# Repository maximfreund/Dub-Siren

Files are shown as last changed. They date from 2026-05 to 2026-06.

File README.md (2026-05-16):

# Dub Siren

> Fork of [xioTechnologies/Dub-Siren](https://github.com/xioTechnologies/Dub-Siren) by [Seb Madgwick](https://github.com/xioTechnologies).
> Changes in this fork: replaced discontinued components, updated BOM, added dub glide bass preset, added simulate.py for sound preview

A monophonic synthesiser comprised of an LFO, VCO, and Delay.  The synthesiser is controlled by 9 potentiometers and 3 buttons.  Configurations can be stored to 1 of 10 preset keys.  Pressing a preset key will override the potentiometers and buttons with the stored configuration.

The processor used is [PIC32MZ](http://www.microchip.com/wwwproducts/en/PIC32MZ2048EFH064).  This is a 32-bit device with a FPU, 512 KB of RAM, 2 MB of program space, running at 252 MHz.  The processor is deliberately over-spec'd to simplify development and allow new ideas to be explored in the future.  The [DAC](https://www.cirrus.com/products/cs4354/) is a 24-bit 192 kHz stereo device configured for 96 kHz mono.

## Synthesiser elements

##### LFO
- Waveforms: sine, triangle, sawtooth, square, stepped triangle, stepped sawtooth
- Shape: adjusts waveform shape
- Frequency: 0 Hz to 15 Hz
- Amplitude: -1 to +1
- Gate control: enable/disable (automatically opens gate after one cycle)

##### VCO
- Waveforms: sine, triangle, sawtooth, square, pulse, 1-bit noise
- Frequency: 0.5 Hz to 5 kHz

##### Delay
- Time: 0 s to 1.33 s
- Feedback: 0% to 100%
- Filter: 3rd-order low-pass with adjustable corner frequency, all-pass (filter disabled), 3rd-order high-pass with adjustable corner frequency

## User instructions (etched on the back panel)



## BOM

* PCBA
* Top plate
* Bottom plate
* Spacer (x4)
* [Row 1, Size 1x1 Cherry MX Keycap](http://www.maxkeyboard.com/row-1-size-1x1-cherry-mx-keycap-r1-1x1.html) (x10)
* [8mm hex stand-off](https://www.digikey.co.uk/products/en?keywords=36-24432-ND) (x4)
* [M3 5mm screw](http://www.ebay.co.uk/itm/M3-BLACK-HIGH-TENSILE-10-9-BUTTON-HEAD-ALLEN-BOLTS-SELF-COLOUR-DOME-SOCKET-SCREW/121829578789) (x4)
* [M3 10mm screw](http://www.ebay.co.uk/itm/M3-BLACK-HIGH-TENSILE-10-9-BUTTON-HEAD-ALLEN-BOLTS-SELF-COLOUR-DOME-SOCKET-SCREW/121829578789) (x4)
* [3M rubber feet](http://www.ebay.co.uk/itm/100x-Silicone-RUBBER-FEET-Bumpons-CLEAR-Round-Self-Adhesive-Anti-Slip-Circles-3M-/172636687398) (x4)

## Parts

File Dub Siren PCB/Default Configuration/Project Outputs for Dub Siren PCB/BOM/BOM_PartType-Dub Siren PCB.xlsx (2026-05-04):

Designator | Quantity | Comment | Footprint
C1, C2, C3, C4, C6, C7, C15, C17, C21 | 9 | 100n, 0603 | Capacitor 0603
C5, C8 | 2 | 22pF, 0603 | Capacitor 0603
C9, C10, C11, C12, C13, C14, C16, C18 | 8 | 2.2uF, 0603 | Capacitor 0603
C19, C20 | 2 | 2.2nF, 0603 | Capacitor 0603
D1, D2 | 2 | XL-302UBD | LED 3mm
D3 | 1 | SA1 | DO-214AC
J1 | 1 | PJ-051A | PJ-051A
J2 | 1 | SSW-116-02-G-D-RA | SSW-116-02-G-D-RA
J3 | 1 | SJ1-3525NG | SJ1-3525NG
R1, R2, R3, R13, R14 | 5 | 4k7, 0603 | Resistor 0603
R4, R5, R6, R7, R8, R9, R10, R11, R12 | 9 | RV09AF-40-20K-B10K | RV09ACF-40
R15, R16 | 2 | 470R, 0603 | Resistor 0603
S1, S2, S3, S4, S5, S6, S7, S8, S9, S10 | 10 | MX1A-E1NW | MX1A
S11, S12, S13 | 3 | FSM14JHX | FSM14JHX
U1 | 1 | PIC32MZ2048EFH064-I/PT | TQFP64
U2 | 1 | UA78M33CDCY | SOT-223
U3 | 1 | UA78M05CDCY | SOT-223
U4 | 1 | CS4354 | SOIC14
U5 | 1 | 24AA32A-I/SN | SOIC8
XT1 | 1 | ABM8-24.000MHZ-B2-T | ABM8

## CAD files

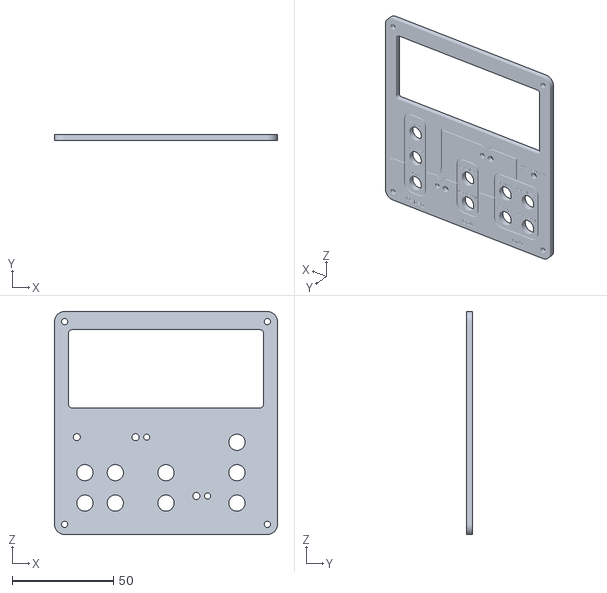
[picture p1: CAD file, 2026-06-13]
Enclosure/Körper1.stl
110.0 x 3.00 x 110.0

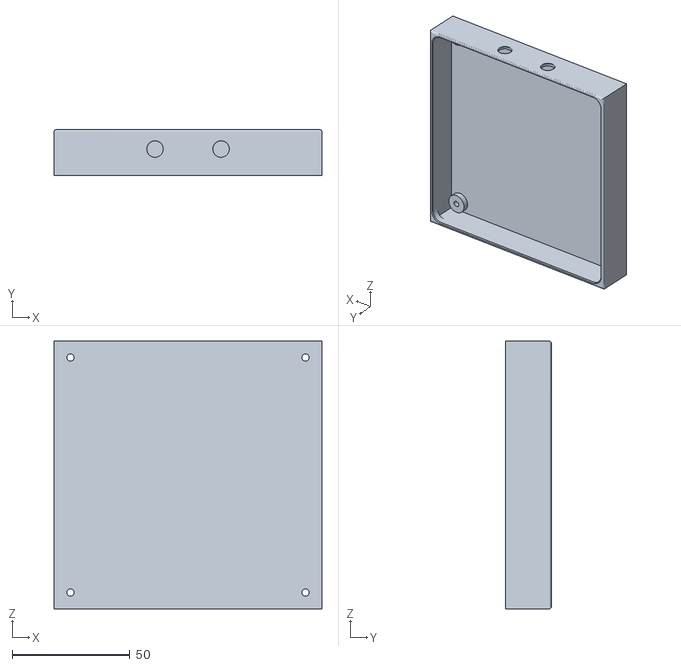
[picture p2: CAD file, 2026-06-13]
Enclosure/UntererTeil.stl
114.0 x 19.5 x 114.0

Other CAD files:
Enclosure/Topplate.3mf

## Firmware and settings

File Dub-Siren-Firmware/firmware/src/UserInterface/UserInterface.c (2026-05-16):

/**
 * @file UserInterface.c
 * @author Seb Madgwick
 * @brief User interface module.
 */

//------------------------------------------------------------------------------
// Includes

#include "DebouncedButton/DebouncedButton.h"
#include "DefaultPresets.h"
#include "Eeprom/Eeprom.h"
#include "I2C/I2cBitBang.h"
#include "IODefinitions.h"
#include <math.h> // fabs, copysignf
#include "MathHelpers.h"
#include "Potentiometers/Potentiometers.h"
#include <stdbool.h>
#include <stdint.h>
#include <stdio.h> // snprintf
#include <string.h> // strlen
#include "Synthesiser/Synthesiser.h"
#include "Timer/Timer.h"
#include "Uart/Uart1.h"
#include "UserInterface/UserInterface.h"

//------------------------------------------------------------------------------
// Definitions

/**
 * @brief Number of preset keys.
 */
#define NUMBER_OF_PRESET_KEYS (10)

/**
 * @brief Minimum VCO frequency in Hz.
 */
#define MINIMUM_VCO_FREQUENCY (5.0f)

/**
 * @brief Maximum VCO frequency in Hz.
 */
#define MAXIMUM_VCO_FREQUENCY (5000.0f)

/**
 * @brief Calculates the cube of a value.
 */
#define CUBE(value) ((value) * (value) * (value))

/**
 * @brief Preset data structure.
 */
typedef struct {
    SynthesiserParameters presets[NUMBER_OF_PRESET_KEYS];
    int32_t checksum;
} EepromData;

//------------------------------------------------------------------------------
// Function prototypes

static void WaitHalfClockCycle();
static void WriteScl(const bool state);
static bool ReadSda();
static void WriteSda(const bool state);
static void LoadPresetsFromEeprom();
static void RestoreDefaultPresets();
static void SavePresetsToFromEeprom();
static void CheckForFactoryReset();
static bool AnyOrAllButtonOrKeyIsHeld(const bool isHeldState);
static void ReadPotentiometers(SynthesiserParameters * const synthesiserParameters);
static int InterpretDiscretePotentiometer(const float potentiometer, const unsigned int numberOfValues, const bool omitDeadbands);
static bool ComparePotentiometers(const float potentiometerA, const float potentiometerB);
static void PrintSynthesiserParameters(const SynthesiserParameters * const synthesiserParameters);
static char* DelayFilterTypeToString(DelayFilterType delayFilterType);
static char* LfoWaveformToString(LfoWaveform lfoWaveform);
static char* VcoWaveformToString(VcoWaveform vcoWaveform);

//------------------------------------------------------------------------------
// Variables

static DebouncedButton triggerSaveButton;
static DebouncedButton lfoGateControlButton;
static DebouncedButton gateButton;
static DebouncedButton presetKeys[NUMBER_OF_PRESET_KEYS];
static I2cBitBang i2cBitBang;
static EepromData eepromData;
static bool ignorePotentiometers;
static bool undoIgnorePotentiometers;

//------------------------------------------------------------------------------
// Functions

/**
 * @brief Initialises module.  This function should be called once, on system
 * start up.
 */
void UserInterfaceInitialise() {

    // Initialise potentiometers to start continuous background ADC conversions
    PotentiometersInitialise();

    // Initialise debounced buttons
    DebouncedButtonInitialise(&triggerSaveButton, &TRIGGER_SAVE_BUTTON_PORT, TRIGGER_SAVE_BUTTON_PORT_BIT);
    DebouncedButtonInitialise(&lfoGateControlButton, &LFO_GATE_CONTROL_BUTTON_PORT, LFO_GATE_CONTROL_BUTTON_PORT_BIT);
    DebouncedButtonInitialise(&gateButton, &GATE_BUTTON_PORT, GATE_BUTTON_PORT_BIT);
    DebouncedButtonInitialise(&presetKeys[0], &PRESET_KEY_1_PORT, PRESET_KEY_1_PORT_BIT);
    DebouncedButtonInitialise(&presetKeys[1], &PRESET_KEY_2_PORT, PRESET_KEY_2_PORT_BIT);
    DebouncedButtonInitialise(&presetKeys[2], &PRESET_KEY_3_PORT, PRESET_KEY_3_PORT_BIT);
    DebouncedButtonInitialise(&presetKeys[3], &PRESET_KEY_4_PORT, PRESET_KEY_4_PORT_BIT);
    DebouncedButtonInitialise(&presetKeys[4], &PRESET_KEY_5_PORT, PRESET_KEY_5_PORT_BIT);
    DebouncedButtonInitialise(&presetKeys[5], &PRESET_KEY_6_PORT, PRESET_KEY_6_PORT_BIT);
    DebouncedButtonInitialise(&presetKeys[6], &PRESET_KEY_7_PORT, PRESET_KEY_7_PORT_BIT);
    DebouncedButtonInitialise(&presetKeys[7], &PRESET_KEY_8_PORT, PRESET_KEY_8_PORT_BIT);
    DebouncedButtonInitialise(&presetKeys[8], &PRESET_KEY_9_PORT, PRESET_KEY_9_PORT_BIT);
    DebouncedButtonInitialise(&presetKeys[9], &PRESET_KEY_10_PORT, PRESET_KEY_10_PORT_BIT);

    // Load presets
    I2CBitBangInitialise(&i2cBitBang, &WaitHalfClockCycle, &WriteScl, &ReadSda, &WriteSda);
    I2CBitBangBusClear(&i2cBitBang);
    LoadPresetsFromEeprom();
}

/**
 * @brief Implements delay for half clock cycle for use by I2C bit-bang.
 */
static void WaitHalfClockCycle() {
    TimerDelayMicroseconds(3);
}

/**
 * @brief Implements write to SCL pin for use by I2C bit-bang.
 * @param state SCL pin state.
 */
static void WriteScl(const bool state) {
    EEPROM_SCL_LAT = state == true ? 1 : 0;
}

/**
 * @brief Implements read of SDA pin for use by I2C bit-bang.
 * @return SDA pin state.
 */
static bool ReadSda() {
    return EEPROM_SDA_PORT == 1;
}

/**
 * @brief Implements write to SDA pin for use by I2C bit-bang.
 * @param state SDA pin state.
 */
static void WriteSda(const bool state) {
    EEPROM_SDA_LAT = state == true ? 1 : 0;
}

/**
 * @brief Loads presets from EEPROM.
 */
static void LoadPresetsFromEeprom() {

    // Read EEPROM data
    EepromRead(&i2cBitBang, 0, (char*) &eepromData, sizeof (eepromData));

    // Verify checksum
    unsigned int index;
    for (index = 0; index < sizeof (eepromData.presets); index++) {
        eepromData.checksum += (int32_t) ((uint8_t*) (&eepromData))[index];
    }
    if (eepromData.checksum == 0) {
        Uart1WriteStringIfReady("\r\nEEPROM checksum OK\r\n");
        return;
    }
    Uart1WriteStringIfReady("\r\nEEPROM checksum FAILED\r\n");

    // Load default presets
    RestoreDefaultPresets();
}

/**
 * @brief Loads default presets.
 */
static void RestoreDefaultPresets() {
    eepromData.presets[0] = fogHorn;
    eepromData.presets[1] = levelUp;
    eepromData.presets[2] = marioCoin;
    eepromData.presets[3] = bombFalling;
    eepromData.presets[4] = policeSiren;
    eepromData.presets[5] = classicDubSirenLow;
    eepromData.presets[6] = dubGlideBass;
    eepromData.presets[7] = classicDubSirenHigh;
    eepromData.presets[8] = bombExploding;
    eepromData.presets[9] = airRaidSiren;
    SavePresetsToFromEeprom();
}

/**
 * @brief Saves presets to EEPROM.
 */
static void SavePresetsToFromEeprom() {

    // Calculate checksum
    eepromData.checksum = 0;
    unsigned int index;
    for (index = 0; index < sizeof (eepromData.presets); index++) {
        eepromData.checksum -= (int32_t) ((uint8_t*) (&eepromData))[index];
    }

    // Write EEPROM data
    EepromWrite(&i2cBitBang, 0, (char*) &eepromData, sizeof (eepromData));
}
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

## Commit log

2026-05-04 Paar sachen in BOM ersetzt
    [BOM_PartType-Dub Siren PCB.xlsx]
2026-05-16 Addes Py simulation, addres 808 wobble glide bass
    [UserInterface.c]
2026-06-13 Sound Adjustments, Enclosure
    [Körper1.stl, Topplate.3mf, UntererTeil.stl]
